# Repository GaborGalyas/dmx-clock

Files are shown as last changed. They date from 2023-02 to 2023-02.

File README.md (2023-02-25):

# DMX controlled Clock
The files here are for making your own DMX controlled clock. Board files, schematics, and source codes can be found here.
# File descriptions:
## 2pix.brd
Printed Circuit Board file created with EAGLE 6.5.0
## 2pix.sch
Schematic file created with EAGLE 6.5.0
## 2pix_top_bom and 2pix_top_cpl 
Bill Of Material and component files what you can upload to a PCB manufacturing site to have your boards assembled
## GGL-CLOCK-FRAME.stl
A 3D printable frame for 2 modules. You need to round the corners of the pcb-s to fit in the corners of the frame. Add a plexiglass to the front with a sheet of frost paper or parchment paper / baking paper between the two. Use M3 bolts from the front to fix the plexi/frost/frame/pcb sandwich together.
## clock_gerbers.zip
Upload this file to a pcb manufacturer site like JLCPCB to have your boards made.
## ggl_clock_dmx_2col.ino
This code is written for an arduino mini with wired dmx input. 
This will need tinkering, you need to connect the arduino to the modules and implement the dmx receiving circuit.
I will work on making a pcb design for a drop in replacement for the wemos d1 mini.
## wireless_clock_wifimanager_2col.ino
This version is for a wemos D1 mini. After assembling the pcb-s solder the wemos d1 mini to the first module, and upload code. For configuration short the D7 pin to ground on boot, and the wifi manager will load. You will be presented with a wireless hotspot named "GGL ARTNET CLOCK CONFIG ME". After connecting, you can configure the wifi network that has Art-Net data coming from the lighting network, and set the dmx address too. Once saved, on every boot the clock will try to connect to the network you provided.

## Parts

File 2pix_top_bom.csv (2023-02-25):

Comment | Designator | Footprint | LCSC Part #
 | C1 C2 C3 C4 C5 C6 C7 C8 C9 C10 C11 C12 C13 C14 C15 C16 C17 C18 C19 C20 C21 C22 C23 C24 C25 C26 C27 C28 C29 C30 C31 C32 C33 C34 C35 C36 C37 C38 C39 C40 C41 C42 | C1206
WS2812B | LED1 LED2 LED3 LED4 LED5 LED6 LED7 LED8 LED9 LED10 LED11 LED12 LED13 LED14 LED15 LED16 LED17 LED18 LED19 LED20 LED21 LED22 LED23 LED24 LED25 LED26 LED27 LED28 LED29 LED30 LED31 LED32 LED33 LED34 LED35 LED36 LED37 LED38 LED39 LED40 LED41 LED42 | WS2812B

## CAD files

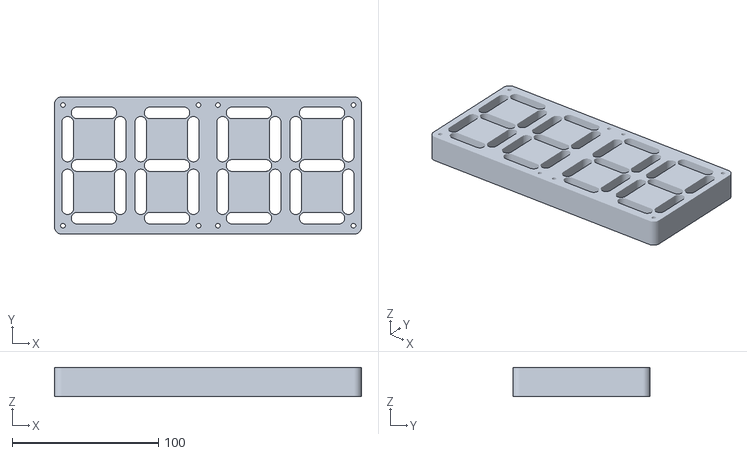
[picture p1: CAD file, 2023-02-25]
GGL-CLOCK-FRAME.stl
210.0 x 94.0 x 20.0

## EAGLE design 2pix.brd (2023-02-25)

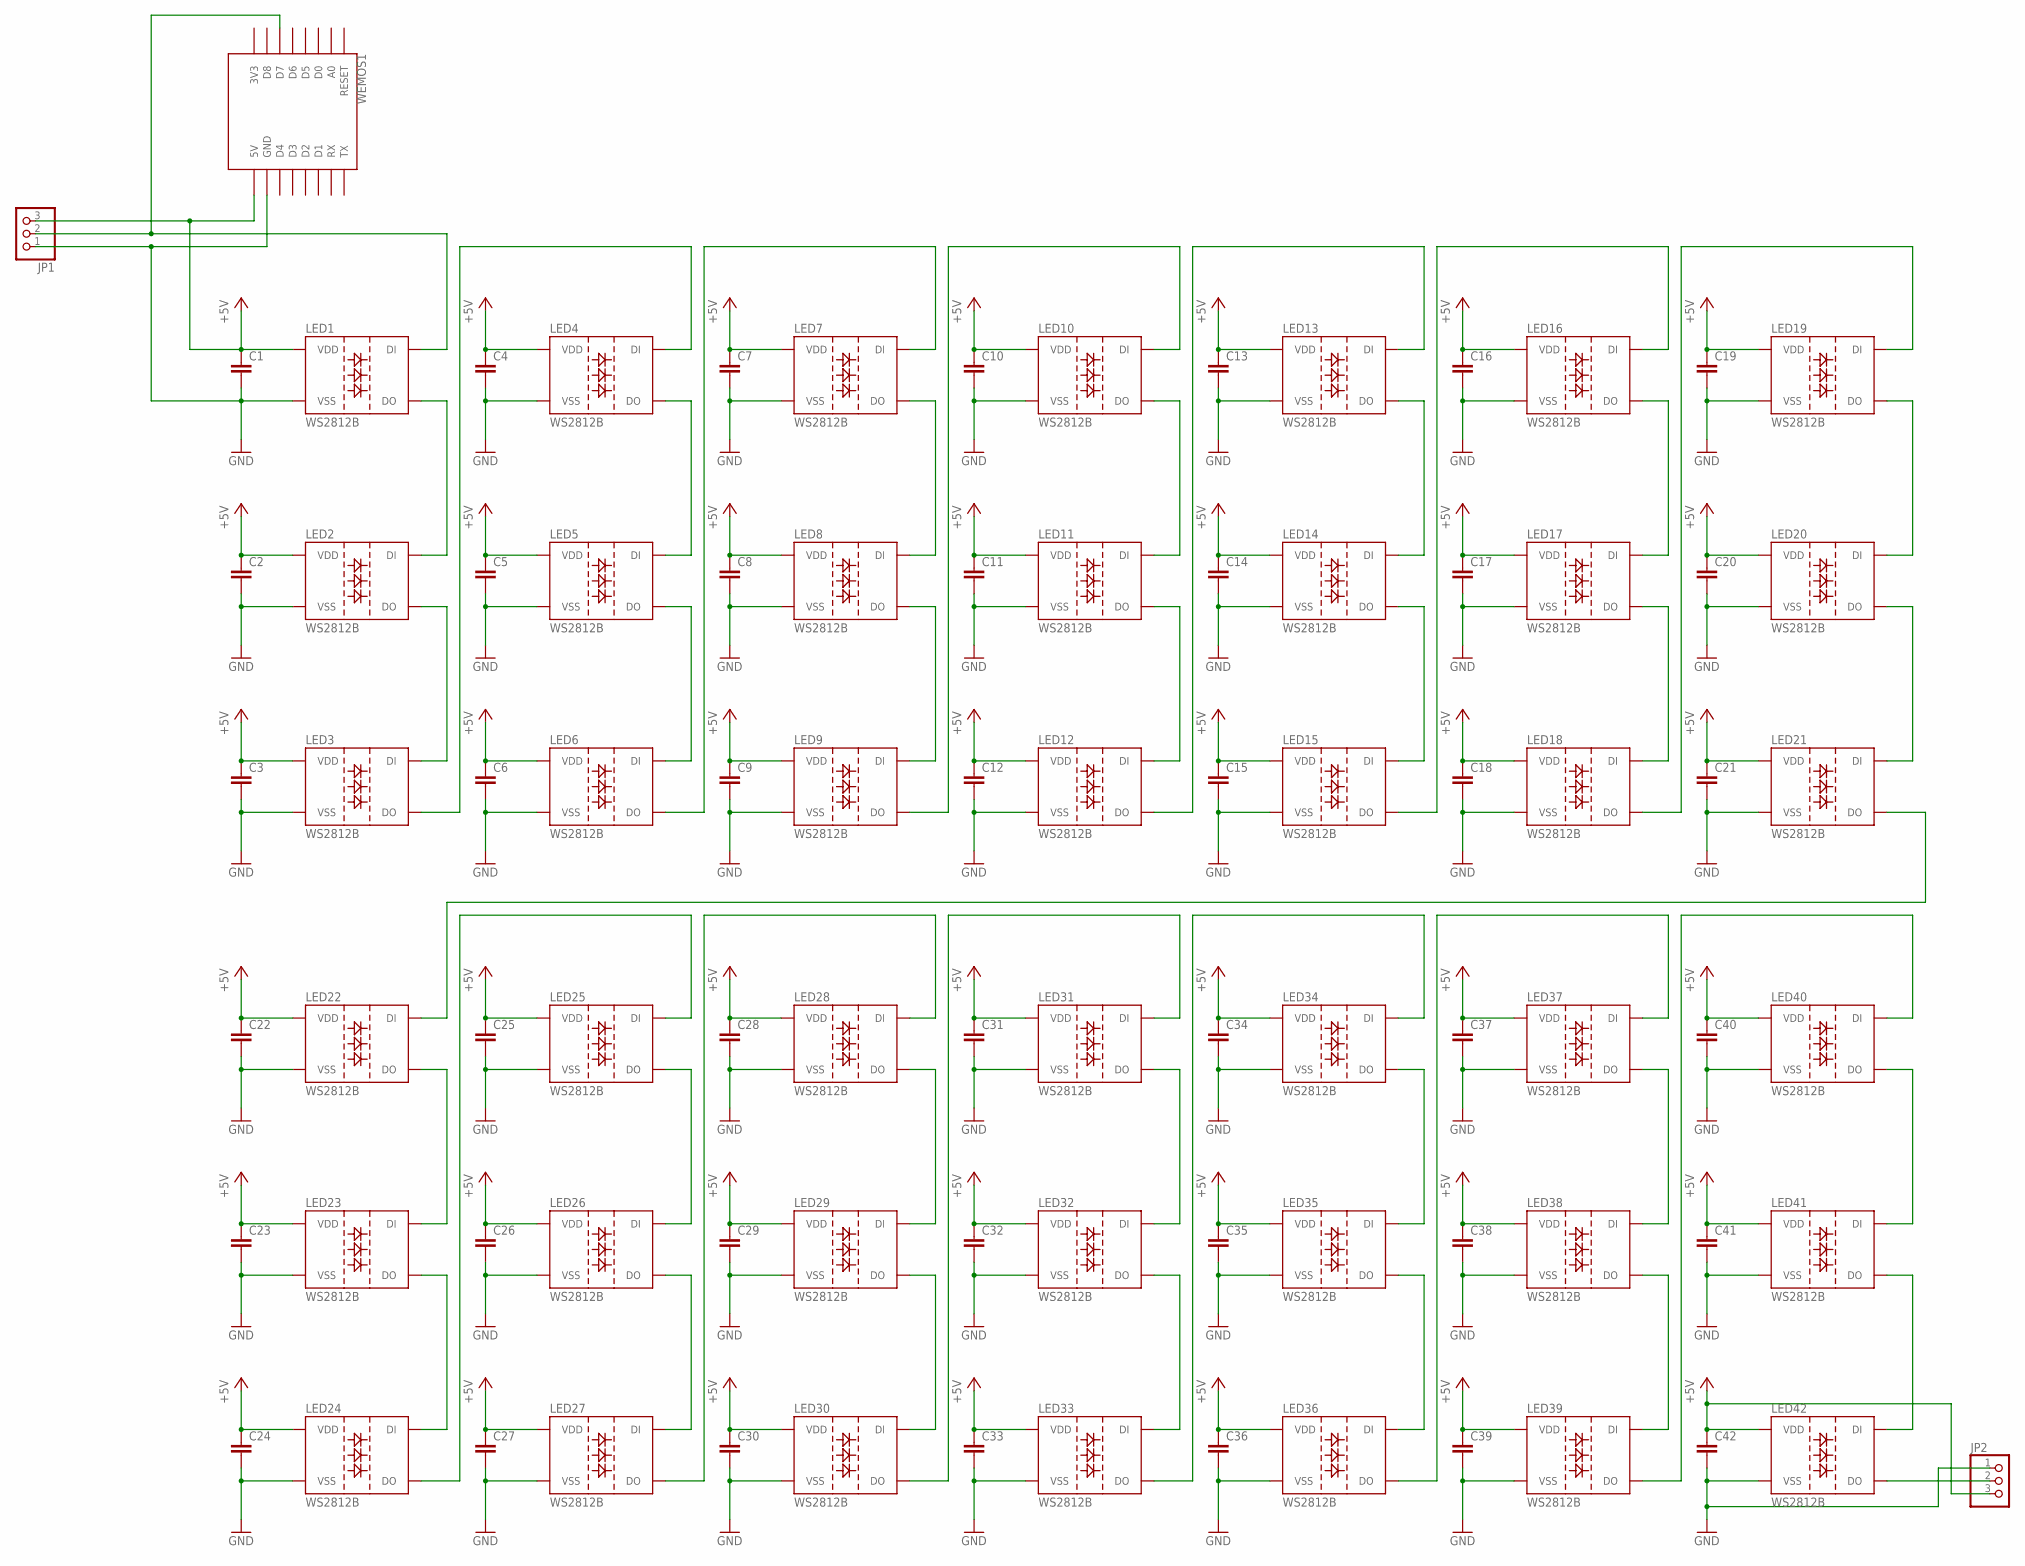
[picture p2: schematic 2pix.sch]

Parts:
C1, C2, C3, C4, C5, C6, C7, C8, C9, C10, C11, C12, C13, C14, C15, C16, C17, C18, C19, C20, C21, C22, C23, C24, C25, C26, C27, C28, C29, C30, C31, C32, C33, C34, C35, C36, C37, C38, C39, C40, C41, C42: C-EUC1206; C1206
JP1, JP2: PINHD-1X3; 1X03
LED1, LED2, LED3, LED4, LED5, LED6, LED7, LED8, LED9, LED10, LED11, LED12, LED13, LED14, LED15, LED16, LED17, LED18, LED19, LED20, LED21, LED22, LED23, LED24, LED25, LED26, LED27, LED28, LED29, LED30, LED31, LED32, LED33, LED34, LED35, LED36, LED37, LED38, LED39, LED40, LED41, LED42: WS2812B
WEMOS1: WEMOS-D1-MINI

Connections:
+5V: C1.1, C2.1, C3.1, C4.1, C5.1, C6.1, C7.1, C8.1, C9.1, C10.1, C11.1, C12.1, C13.1, C14.1, C15.1, C16.1, C17.1, C18.1, C19.1, C20.1, C21.1, C22.1, C23.1, C24.1, C25.1, C26.1, C27.1, C28.1, C29.1, C30.1, C31.1, C32.1, C33.1, C34.1, C35.1, C36.1, C37.1, C38.1, C39.1, C40.1, C41.1, C42.1, JP1.3, JP2.3, LED1.1 (VDD), LED2.1 (VDD), LED3.1 (VDD), LED4.1 (VDD), LED5.1 (VDD), LED6.1 (VDD), LED7.1 (VDD), LED8.1 (VDD), LED9.1 (VDD), LED10.1 (VDD), LED11.1 (VDD), LED12.1 (VDD), LED13.1 (VDD), LED14.1 (VDD), LED15.1 (VDD), LED16.1 (VDD), LED17.1 (VDD), LED18.1 (VDD), LED19.1 (VDD), LED20.1 (VDD), LED21.1 (VDD), LED22.1 (VDD), LED23.1 (VDD), LED24.1 (VDD), LED25.1 (VDD), LED26.1 (VDD), LED27.1 (VDD), LED28.1 (VDD), LED29.1 (VDD), LED30.1 (VDD), LED31.1 (VDD), LED32.1 (VDD), LED33.1 (VDD), LED34.1 (VDD), LED35.1 (VDD), LED36.1 (VDD), LED37.1 (VDD), LED38.1 (VDD), LED39.1 (VDD), LED40.1 (VDD), LED41.1 (VDD), LED42.1 (VDD), WEMOS1.5V
GND: C1.2, C2.2, C3.2, C4.2, C5.2, C6.2, C7.2, C8.2, C9.2, C10.2, C11.2, C12.2, C13.2, C14.2, C15.2, C16.2, C17.2, C18.2, C19.2, C20.2, C21.2, C22.2, C23.2, C24.2, C25.2, C26.2, C27.2, C28.2, C29.2, C30.2, C31.2, C32.2, C33.2, C34.2, C35.2, C36.2, C37.2, C38.2, C39.2, C40.2, C41.2, C42.2, JP1.1, JP2.1, LED1.3 (VSS), LED2.3 (VSS), LED3.3 (VSS), LED4.3 (VSS), LED5.3 (VSS), LED6.3 (VSS), LED7.3 (VSS), LED8.3 (VSS), LED9.3 (VSS), LED10.3 (VSS), LED11.3 (VSS), LED12.3 (VSS), LED13.3 (VSS), LED14.3 (VSS), LED15.3 (VSS), LED16.3 (VSS), LED17.3 (VSS), LED18.3 (VSS), LED19.3 (VSS), LED20.3 (VSS), LED21.3 (VSS), LED22.3 (VSS), LED23.3 (VSS), LED24.3 (VSS), LED25.3 (VSS), LED26.3 (VSS), LED27.3 (VSS), LED28.3 (VSS), LED29.3 (VSS), LED30.3 (VSS), LED31.3 (VSS), LED32.3 (VSS), LED33.3 (VSS), LED34.3 (VSS), LED35.3 (VSS), LED36.3 (VSS), LED37.3 (VSS), LED38.3 (VSS), LED39.3 (VSS), LED40.3 (VSS), LED41.3 (VSS), LED42.3 (VSS), WEMOS1.GND
unnamed: LED4.2 (DO), LED5.4 (DI)
unnamed: LED1.2 (DO), LED2.4 (DI)
unnamed: LED3.2 (DO), LED4.4 (DI)
unnamed: LED2.2 (DO), LED3.4 (DI)
unnamed: LED5.2 (DO), LED6.4 (DI)
unnamed: LED6.2 (DO), LED7.4 (DI)
unnamed: LED7.2 (DO), LED8.4 (DI)
unnamed: LED9.2 (DO), LED10.4 (DI)
unnamed: LED8.2 (DO), LED9.4 (DI)
unnamed: LED10.2 (DO), LED11.4 (DI)
unnamed: LED11.2 (DO), LED12.4 (DI)
unnamed: LED12.2 (DO), LED13.4 (DI)
unnamed: LED13.2 (DO), LED14.4 (DI)
unnamed: LED15.2 (DO), LED16.4 (DI)
unnamed: LED14.2 (DO), LED15.4 (DI)
unnamed: LED16.2 (DO), LED17.4 (DI)
unnamed: LED17.2 (DO), LED18.4 (DI)
unnamed: LED18.2 (DO), LED19.4 (DI)
unnamed: LED19.2 (DO), LED20.4 (DI)
unnamed: LED21.2 (DO), LED22.4 (DI)
unnamed: LED20.2 (DO), LED21.4 (DI)
unnamed: LED22.2 (DO), LED23.4 (DI)
unnamed: LED24.2 (DO), LED25.4 (DI)
unnamed: LED23.2 (DO), LED24.4 (DI)
unnamed: LED25.2 (DO), LED26.4 (DI)
unnamed: LED26.2 (DO), LED27.4 (DI)
unnamed: LED27.2 (DO), LED28.4 (DI)
unnamed: LED28.2 (DO), LED29.4 (DI)
unnamed: LED30.2 (DO), LED31.4 (DI)
unnamed: LED29.2 (DO), LED30.4 (DI)
unnamed: LED31.2 (DO), LED32.4 (DI)
unnamed: LED32.2 (DO), LED33.4 (DI)
unnamed: LED33.2 (DO), LED34.4 (DI)
unnamed: LED34.2 (DO), LED35.4 (DI)
unnamed: LED36.2 (DO), LED37.4 (DI)
unnamed: LED35.2 (DO), LED36.4 (DI)
unnamed: LED37.2 (DO), LED38.4 (DI)
unnamed: LED38.2 (DO), LED39.4 (DI)
unnamed: LED39.2 (DO), LED40.4 (DI)
unnamed: LED40.2 (DO), LED41.4 (DI)
unnamed: JP1.2, LED1.4 (DI), WEMOS1.D7
unnamed: LED41.2 (DO), LED42.4 (DI)
unnamed: JP2.2, LED42.2 (DO)

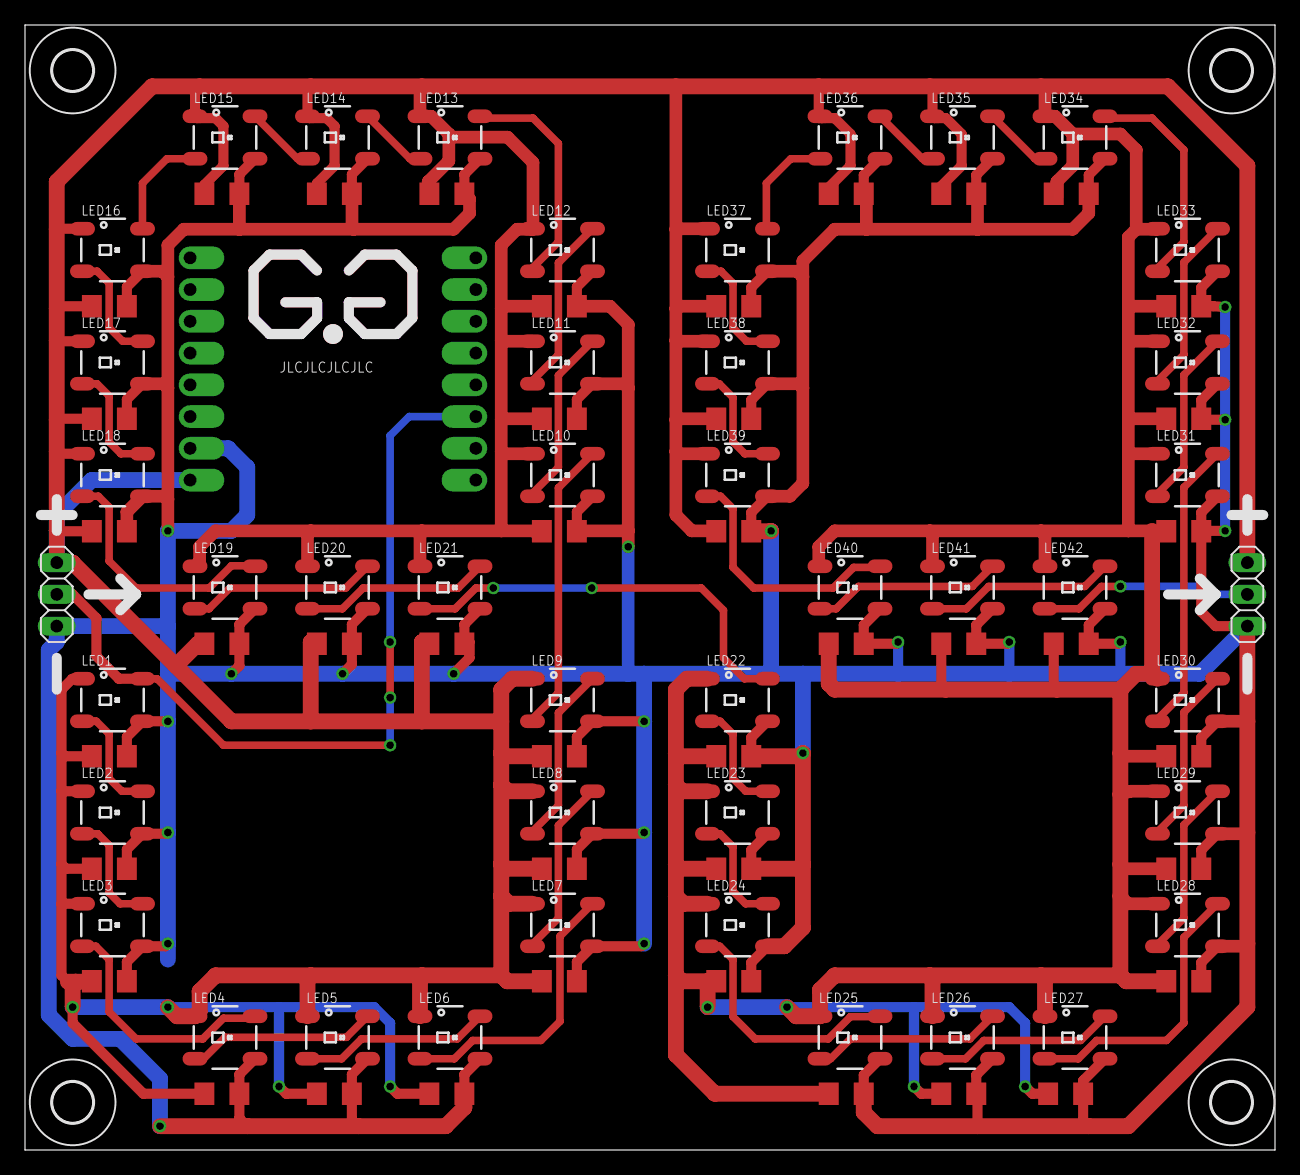
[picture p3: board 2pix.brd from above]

Board: 2 copper layers, 100.0 x 90.0 mm, 91 parts (1 on the bottom side), 45 nets.

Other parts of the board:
U$1, U$2, U$3, U$4: 3,2

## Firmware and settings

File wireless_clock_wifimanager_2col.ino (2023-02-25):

//This version is for a wemos D1 mini. After assembling the pcb-s solder the wemos d1 mini to the first module, and upload code
//For configuration short the D7 pin to ground on boot, and the wifi manager will load.
//You will be presented with a wireless hotspot named "GGL ARTNET CLOCK CONFIG ME". After connecting, you can configure the wifi network that has Art-Net data
//coming from the lighting network, and set the dmx address too. Once saved, on every boot the clock will try to connect to the network you provided.

// Install all these libraries...
#include <FastLED.h>
#include <WiFiUdp.h>
#include <ESP8266WiFi.h>
#include <DNSServer.h>
#include <ESP8266WebServer.h>
#include <WiFiManager.h>
#include <EEPROM.h>

char dmxstart[5];
int startaddress;
IPAddress ip(EEPROM.read(1),EEPROM.read(2),EEPROM.read(3),EEPROM.read(4));
IPAddress gw(EEPROM.read(5),EEPROM.read(6),EEPROM.read(7),EEPROM.read(8));
IPAddress sn(EEPROM.read(9),EEPROM.read(10),EEPROM.read(11),EEPROM.read(12));

int ipa;
int ipb;
int ipc;
int ipd;
int gwa;
int gwb;
int gwc;
int gwd;
int sna;
int snb;
int snc;
int snd;


bool shouldSaveConfig = false;

void saveConfigCallback () {
  Serial.println("Should save config");
  shouldSaveConfig = true;
}



#define ARTNET_DATA 0x50
#define ARTNET_POLL 0x20
#define ARTNET_POLL_REPLY 0x21
#define ARTNET_PORT 6454
#define ARTNET_HEADER 17

WiFiUDP udp;

uint8_t uniData[514];
uint16_t uniSize;
uint8_t hData[ARTNET_HEADER + 1];
uint8_t net = 0;
uint8_t universe = 0;
uint8_t subnet = 0;

#define NUM_LEDS 84
#define DATA_PIN 13 //D7
CRGB leds[NUM_LEDS];

unsigned long lastpacket = 1000;
const long packetinterval = 1000;

int dmxcol[6] = {0, 0, 0, 0, 0, 0};

int inpin = 14;  //D5  wifi reset

int d1 = 0;
int d2 = 21;
int d3 = 42;
int d4 = 63;

byte digits[10][21] = {
     {1,1,1 ,1,1,1 ,1,1,1 ,1,1,1 ,1,1,1 ,1,1,1 ,0,0,0} //0 
    ,{0,0,0 ,0,0,0 ,1,1,1 ,1,1,1 ,0,0,0 ,0,0,0 ,0,0,0} //1
    ,{1,1,1 ,1,1,1 ,0,0,0 ,1,1,1 ,1,1,1 ,0,0,0 ,1,1,1} //2
    ,{0,0,0 ,1,1,1 ,1,1,1 ,1,1,1 ,1,1,1 ,0,0,0 ,1,1,1} //3
    ,{0,0,0 ,0,0,0 ,1,1,1 ,1,1,1 ,0,0,0 ,1,1,1 ,1,1,1} //4
    ,{0,0,0 ,1,1,1 ,1,1,1 ,0,0,0 ,1,1,1 ,1,1,1 ,1,1,1} //5
    ,{1,1,1 ,1,1,1 ,1,1,1 ,0,0,0 ,1,1,1 ,1,1,1 ,1,1,1} //6
    ,{0,0,0 ,0,0,0 ,1,1,1 ,1,1,1 ,1,1,1 ,0,0,0 ,0,0,0} //7
    ,{1,1,1 ,1,1,1 ,1,1,1 ,1,1,1 ,1,1,1 ,1,1,1 ,1,1,1} //8
    ,{0,0,0 ,1,1,1 ,1,1,1 ,1,1,1 ,1,1,1 ,1,1,1 ,1,1,1} //9
   };

void setup() {
 // WiFi.mode(WIFI_STA);
  FastLED.addLeds<NEOPIXEL, DATA_PIN>(leds, NUM_LEDS);  // GRB ordering is assumed 
    FastLED.setBrightness(255);
    thchase();
  Serial.begin(115200);
  EEPROM.begin(512);
    thchase();
    pinMode(inpin, INPUT_PULLUP);      
    WiFiManager wifiManager;
    wifiManager.setClass("invert"); // dark theme
    WiFiManagerParameter custom_dmxstart("Address", "Address", dmxstart, 5);
    wifiManager.addParameter(&custom_dmxstart);
     if (digitalRead(inpin) == LOW){
        wifiManager.resetSettings(); 
        EEPROM.write(1, 2);
        EEPROM.write(2, 12);
        EEPROM.write(3, 13);
        EEPROM.write(4, 14);
        EEPROM.write(5, 2);
        EEPROM.write(6, 0);
        EEPROM.write(7, 0);
        EEPROM.write(8, 1);
        EEPROM.write(9, 255);
        EEPROM.write(10, 0);
        EEPROM.write(11, 0);
        EEPROM.write(12, 0);
        EEPROM.write(13, 5);
        EEPROM.write(14, 0);
        EEPROM.write(15, 5);
        EEPROM.commit();
      }
ipa = EEPROM.read(1);
ipb = EEPROM.read(2);
ipc = EEPROM.read(3);
ipd = EEPROM.read(4);
gwa = EEPROM.read(5);
gwb = EEPROM.read(6);
gwc = EEPROM.read(7);
gwd = EEPROM.read(8);
sna = EEPROM.read(9);
snb = EEPROM.read(10);
snc = EEPROM.read(11);
snd = EEPROM.read(12);
getstart();
wifiManager.setSaveConfigCallback(saveConfigCallback);
wifiManager.setSTAStaticIPConfig(IPAddress(ipa,ipb,ipc,ipd), IPAddress(gwa, gwb, gwc, gwd), IPAddress(sna, snb, snc, snd));
thchase();
wifiManager.setConnectTimeout(200);
wifiManager.setTimeout(200);
thchase();
wifiManager.autoConnect("GGL ARTNET CLOCK CONFIG ME");
 if (shouldSaveConfig) {   
IPAddress ip = WiFi.localIP();
IPAddress gw = WiFi.gatewayIP();
IPAddress sn = WiFi.subnetMask();
    Serial.println("saving config");
    
strcpy(dmxstart, custom_dmxstart.getValue());

EEPROM.write(1, ip[0]);
EEPROM.write(2, ip[1]);
EEPROM.write(3, ip[2]);
EEPROM.write(4, ip[3]);
EEPROM.write(5, gw[0]);
EEPROM.write(6, gw[1]);
EEPROM.write(7, gw[2]);
EEPROM.write(8, gw[3]);
EEPROM.write(9, sn[0]);
EEPROM.write(10, sn[1]);
EEPROM.write(11, sn[2]);
EEPROM.write(12, sn[3]);
EEPROM.write(13, dmxstart[0]);
EEPROM.write(14, dmxstart[1]);
EEPROM.write(15, dmxstart[2]);
Serial.println("saving address");
Serial.println(dmxstart[0]);
Serial.println(dmxstart[1]);
Serial.println(dmxstart[2]);
EEPROM.commit();
configdash();
delay(2000);
// ESP.reset();
    //end save
  }

    ESP.wdtDisable(); 
    ESP.wdtEnable(WDTO_8S);
    getstart();
    Serial.print("Starting with: ");
    Serial.println(startaddress);
    udp.begin(ARTNET_PORT); // Open ArtNet port
//    WiFi.softAPdisconnect (true);
 WiFi.softAP("GGL CLOCK", "506c616e42", 1, 0);
}

void loop() {
  ESP.wdtFeed();
  lastpacket = lastpacket + 1;
  if (lastpacket >= packetinterval){
      nosig();
  }
  
   if (udp.parsePacket()) {
    udp.read(hData, ARTNET_HEADER + 1);
    if ( hData[0] == 'A' && hData[1] == 'r' && hData[2] == 't' && hData[3] == '-' && hData[4] == 'N' && hData[5] == 'e' && hData[6] == 't') {
      if ( hData[8] == 0x00 && hData[9] == ARTNET_DATA && hData[15] == net ) {
        if ( hData[14] == (subnet << 4) + universe ) { // UNIVERSE
          uniSize = (hData[16] << 8) + (hData[17]);
          udp.read(uniData, uniSize);
        dmxcol[0] = uniData[(startaddress-1)];         
        dmxcol[1] = uniData[startaddress];         
        dmxcol[2] = uniData[(startaddress+1)];
        dmxcol[3] = uniData[(startaddress+2)];
        dmxcol[4] = uniData[(startaddress+3)];
        dmxcol[5] = uniData[(startaddress+4)];
        module(uniData[(startaddress+5)],uniData[(startaddress+6)]);
        lastpacket = 0;        
        FastLED.show();
        }
      }
    }
  } 
  delay(10);
}

void PrintNumber(byte number, int offset){
  if( number>10 )
    return;
  for(int i=0; i<21; i++){
    if( digits[number][i] )
    if ( offset >= 40){
      leds[i+offset].setRGB(dmxcol[3],dmxcol[4],dmxcol[5]);  //Switch the LED on
    }else{
      leds[i+offset].setRGB(dmxcol[0],dmxcol[1],dmxcol[2]);  //Switch the LED on
    }
      
    else
      leds[i+offset] = CRGB::Black; // Switch the LED off
  }
}

void module( int mins, int secs){
uint16_t totaltime = (mins << 8) + (secs);  
uint16_t mapval = map(totaltime, 0, 65535, 0, 3600);
int dmin = mapval/60;
int dsec = mapval - (dmin * 60);
    PrintNumber(((dmin/10)%10),d1);
    PrintNumber((dmin%10),d2);   
    PrintNumber(((dsec/10)%10),d3);
    PrintNumber((dsec%10),d4);
}
void thchase() {
    leds[18+d1] = CRGB::Red;
    leds[19+d1] = CRGB::Red;
    leds[20+d1] = CRGB::Red;
    leds[18+d2] = CRGB::Red;
    leds[19+d2] = CRGB::Red;
    leds[20+d2] = CRGB::Red;
    leds[18+d3] = CRGB::Red;
    leds[19+d3] = CRGB::Red;
    leds[20+d3] = CRGB::Red;
    leds[18+d4] = CRGB::Red;
    leds[19+d4] = CRGB::Red;
    leds[20+d4] = CRGB::Red;
    for(int p = 0; p < 18; p++) {
      leds[p+d1] = CRGB::Blue;
      leds[p+d1].maximizeBrightness();  
      leds[p+d2] = CRGB::Blue;
      leds[p+d2].maximizeBrightness();
      leds[p+d3] = CRGB::Blue;
      leds[p+d3].maximizeBrightness();
      leds[p+d4] = CRGB::Blue;
      leds[p+d4].maximizeBrightness();
      FastLED.show();
      FastLED.delay(30);
      leds[p+d1].setRGB(200,50,0);
      leds[p+d1].fadeLightBy( 128 );
      leds[p+d2].setRGB(200,50,0);
      leds[p+d2].fadeLightBy( 128 );
      leds[p+d3].setRGB(200,50,0);
      leds[p+d3].fadeLightBy( 128 );
      leds[p+d4].setRGB(200,50,0);
      leds[p+d4].fadeLightBy( 128 );
     }
}
void nosig(){
  for(int l = 0; l < 84; l++) {
      leds[l] = CRGB::Black;
  }
  for(int n = 18; n < 21; n++) {
      leds[n+d1] = CRGB::Red;
      leds[n+d2] = CRGB::Red;
      leds[n+d3] = CRGB::Red;
      leds[n+d4] = CRGB::Red;
     } 
      FastLED.show();
}
void configdash(){
  for(int l = 0; l < 84; l++) {
      leds[l] = CRGB::Black;
  }
  for(int n = 18; n < 21; n++) {
      leds[n+d2] = CRGB::Green;
      leds[n+d3] = CRGB::Green;
     } 
      FastLED.show();
}
void getstart(){
  char buffer[4];
buffer[0] = EEPROM.read(13);
buffer[1] = EEPROM.read(14);
buffer[2] = EEPROM.read(15);
buffer[3] = '\0';
startaddress = atoi(buffer); 
}
